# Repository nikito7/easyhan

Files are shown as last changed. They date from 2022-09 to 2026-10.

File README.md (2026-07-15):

# Easy HAN ®

Smart IoT Devices

- [```bridge``` rtuovertcp modbus tcp](./tasmota/bridge/)

- [```edpbox V1``` contadores inteligentes](./V1/)

- [```edpbox V2``` contadores inteligentes](./V2/)

- [```growatt``` inversor solar](./tasmota/growatt/)

- [```lorawan``` ttn edpbox han](./misc/lorawan/)

____
Sansana Smart Solutions ® Portugal

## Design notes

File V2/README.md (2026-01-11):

# HAN V2

https://github.com/nikito7/han-dev/tree/dev/tasmota/xdrv100

EB1:
https://u.easyhan.pt/v2/setup-v2/

Deve-se usar os ficheiros do u.easyhan.pt

Os ficheiros do github acima, são apenas para seguir o desenvolvimento.

# Override Settings

Tools > Manage filesystem <br>
Criar o ficheiro config.txt

```js
HanDelayWait 1000
HanDelayError 5000
HanTimeout 1500
HanRestart 0
TelePeriod 10
HanSkip 0,0,0,0,0,0,0,0,0,0,0,0,0,0,0
```

O ficheiro só é aplicado aos 30 segundos depois de iniciado.

# HanSkip

HanSkip 0,0,0,0,0,0,0,0,0,0,0,0,0,0,0

```js
1 - EB Type
2 - EMI Info
3 - Contract
4 - LP ID
5 - Clock
6 - Voltage. Current.
7 - Power. Power Factor mono.
8 - Power Factor tri. Frequency mono.
9 - kWh Energy Tarifas
10 - kWh Total Energy
11 - kWh L1 L2 L3 
12 - Reserved
13 - Load Profile
14 - Ciclo. Tarifa.
15 - ICP Status
```

Apenas Watts:

```js
HanSkip 1,1,1,1,1,1,0,1,1,1,1,1,1,1,1
```
Realtime Netmetering (qs):

```js
HanSkip 1,1,1,1,0,1,0,1,1,0,1,1,1,1,1
```

Tudo a cada 5min (script);

```js
>S

if (upsecs%300==0 and upsecs>100)
{
=>BackLog HanSkip 0,0; Delay 200; HanSkip 1,1,1,1,1,1,0,1,1,1,1,1,1,1,1
}
```

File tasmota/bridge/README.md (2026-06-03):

⚠️ Easy HAN E5.1 Enable pin GPIO16

V2: firmware *-tcp

https://u.easyhan.pt/v2/

V1: default

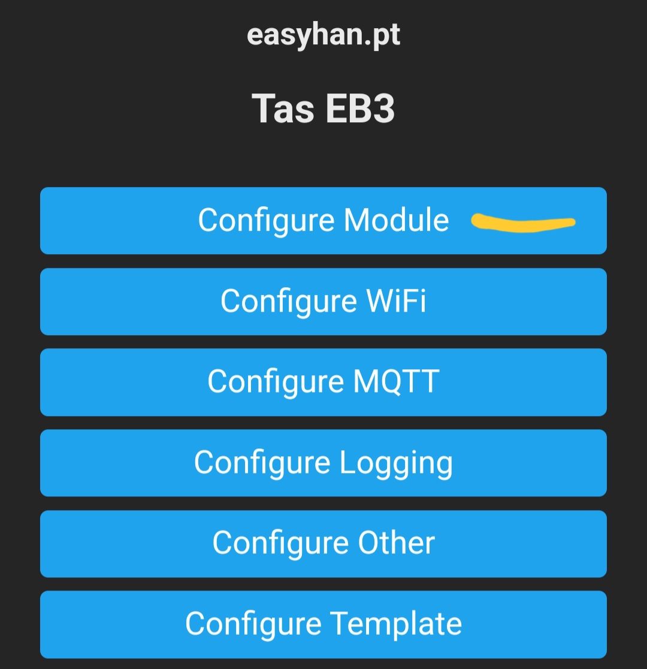
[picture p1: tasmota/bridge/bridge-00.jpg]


RTU over TCP:

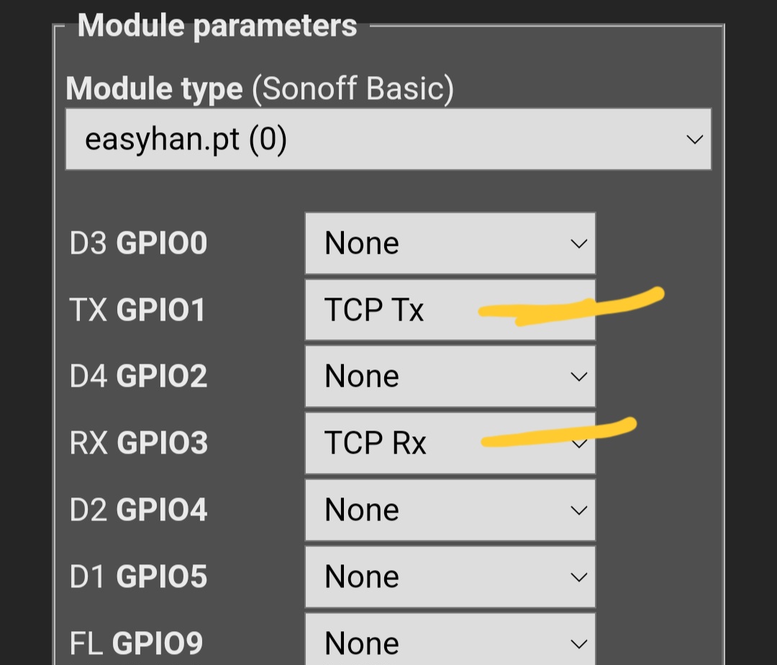
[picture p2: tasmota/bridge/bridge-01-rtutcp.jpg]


https://github.com/nikito7/easyhan/blob/dev/tasmota/bridge/Bridge-RTUoverTCP.js

Modbus TCP:

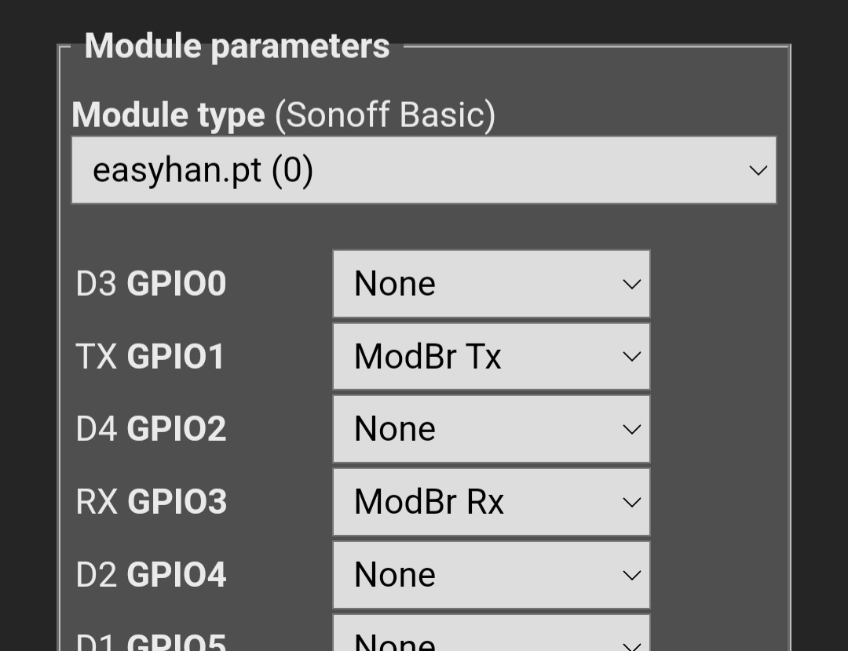
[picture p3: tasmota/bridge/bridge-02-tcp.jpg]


https://github.com/nikito7/easyhan/blob/dev/tasmota/bridge/Bridge-ModbusTCP.js

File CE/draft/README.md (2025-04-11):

# Links

https://europa.eu/youreurope/business/product-requirements/labels-markings/ce-marking/index_en.htm

# Technical documentation (draft)

**Product function:**

  Generic modbus to WiFi converter.

**Product names and models:**

- Easy HAN ® E5 WiFi
- Easy HAN ® B5 WiFi

**Product version**:

  5.4.1

**Markets:**

  Portugal, EU.

**PCB board design:**

  Coimbra, Portugal.

**PCB board manufacturing, components source and SMT assembly:**

  JLCPCB, China.

**Final prototype assembly:**

  Coimbra, Portugal.

**Status of development:**

  Final prototype.

2025-04-11

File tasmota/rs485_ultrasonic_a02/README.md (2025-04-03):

wires:

```
Red = 5V
Black = Ground
White = A+
Yellow = B-
```

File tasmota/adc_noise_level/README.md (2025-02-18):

https://circuitdigest.com/microcontroller-projects/interface-ky038-sound-sensor-with-esp32

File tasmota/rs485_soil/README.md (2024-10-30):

# Soil Sensor RS485

ZTS-3000-TR-WS-N01

# ESPHome

https://github.com/nikito7/easyhan/blob/dev/esphome/t44-x04-soil.yaml

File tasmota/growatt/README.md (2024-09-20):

Tutorial:

https://forum.cpha.pt/t/integrar-inversor-growatt-tl3-no-home-assistant/10672

 

FreeDS:

mqtt: freeds/growatt/SENSOR

---

Growatt inversor

Modbus RS485

---

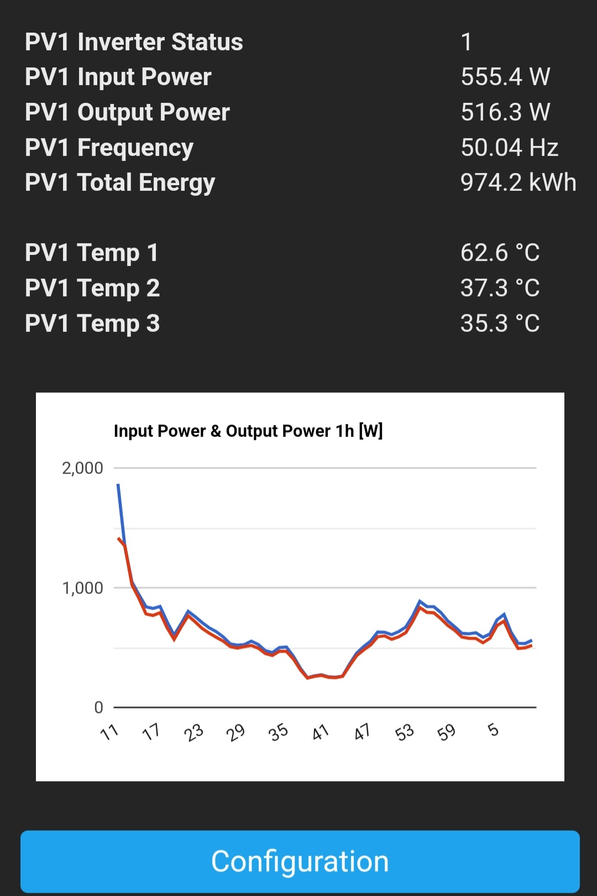
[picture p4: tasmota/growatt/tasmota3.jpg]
inverter tasmota


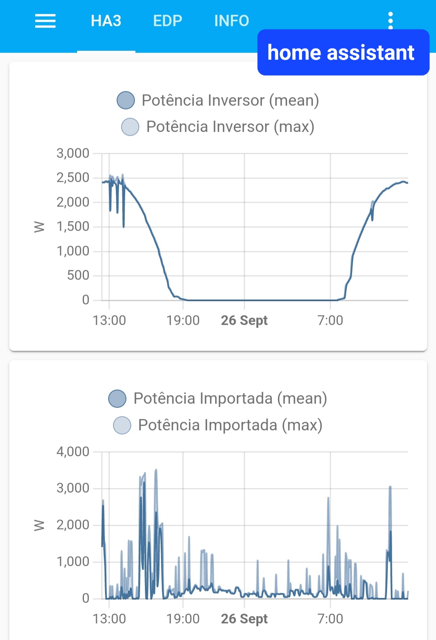
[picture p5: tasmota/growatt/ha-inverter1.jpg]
Easy HAN inverter


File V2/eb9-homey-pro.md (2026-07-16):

# Homey Pro

https://homey.app/

Requisitos:
- MQTT Broker (server)
- MQTT Client
- MQTT Hub (virtual devices)

# EB1 (monofásico)

```
{
  "measure_power": {
    "capability": "measure_power",
    "stateTopic": "tele/edpbox1/SENSOR",
    "setTopic": "",
    "valueTemplate": "EB1.API - EB1.APE",
    "outputTemplate": "",
    "displayName": "Power"
  },
  "meter_power.imported": {
    "capability": "meter_power.imported",
    "stateTopic": "tele/edpbox1/SENSOR",
    "setTopic": "",
    "valueTemplate": "EB1.TEI",
    "outputTemplate": "",
    "displayName": "Energy Import"
  },
  "meter_power.exported": {
    "capability": "meter_power.exported",
    "stateTopic": "tele/edpbox1/SENSOR",
    "setTopic": "",
    "valueTemplate": "EB1.TEE",
    "outputTemplate": "",
    "displayName": "Energy Export"
  }
}
```

# EB3 (trifásico)

```
{
  "measure_power": {
    "capability": "measure_power",
    "stateTopic": "tele/edpbox3/SENSOR",
    "setTopic": "",
    "valueTemplate": "EB3.API - EB3.APE",
    "outputTemplate": "",
    "displayName": "Power"
  },
  "meter_power.imported": {
    "capability": "meter_power.imported",
    "stateTopic": "tele/edpbox3/SENSOR",
    "setTopic": "",
    "valueTemplate": "EB3.TEI",
    "outputTemplate": "",
    "displayName": "Energy Import"
  },
  "meter_power.exported": {
    "capability": "meter_power.exported",
    "stateTopic": "tele/edpbox3/SENSOR",
    "setTopic": "",
    "valueTemplate": "EB3.TEE",
    "outputTemplate": "",
    "displayName": "Energy Export"
  }
}

# PV1

{
  "measure_power": {
    "capability": "measure_power",
    "stateTopic": "tele/pv1/SENSOR",
    "setTopic": "",
    "valueTemplate": "PV1.InputPower",
    "outputTemplate": "",
    "displayName": "Power"
  },
  "meter_power": {
    "capability": "meter_power",
    "stateTopic": "tele/pv1/SENSOR",
    "setTopic": "",
    "valueTemplate": "PV1.PV_Energy",
    "outputTemplate": "",
    "displayName": "Energy"
  }
}
```

_____
EOF

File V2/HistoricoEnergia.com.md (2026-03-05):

# historicoenergia.com

https://historicoenergia.com

Acrescentar os blocos de código ao Script, no sitio correcto.

# Script B5

```
>D 48
...
```
```js
;
TOK="token"
ID="ebhan"
T=0
E1=0
E2=0
E3=0
F=0
I=0
PF=0
```

EB3:

```
>T
...
```
```js
;
T=EB3#Tariff
E1=EB3#TET1
E2=EB3#TET2
E3=EB3#TET3
I=EB3#CL
F=EB3#FR
PF=EB3#PF
```

EB1:

```
>T
...
```
```js
;
T=EB1#Tariff
E1=EB1#TET1
E2=EB1#TET2
E3=EB1#TET3
I=EB1#CL1
F=EB1#FR
PF=EB1#PF
```

```
>S
...
```
```js
if (upsecs%181==0 and cnt>40)
{
print historicoenergia.com %2.0hh%:%2.0mm%:%2.0ss%
->WebQuery http://api.historicoenergia.com/api/webhook/mqtt?deviceId=%ID%&token=%TOK% POST {"P":%0ipwr%,"V":%1vt1%,"T":%0T%,"E1":%2E1%,"E2":%2E2%,"E3":%2E3%,"F":%1F%,"PF":%PF%,"I":%1I%}
}
```

# Script E5 basico

```
>S
...
```
```js
if (upsecs%181==0 and cnt>40)
{
print historicoenergia.com %2.0hh%:%2.0mm%:%2.0ss%
->WebQuery http://api.historicoenergia.com/api/webhook/mqtt?deviceId=DEVICE&token=TOKEN POST {"P":%0ipwr%,"V":%1vt1%}
}
```

# EOF

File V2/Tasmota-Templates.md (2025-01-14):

# Tasmota Templates

> B5.02
> ESP32-C6 N8

```{"NAME":"sd.c6.easyhan.pt","GPIO":[1,1,1,1,1,1,1,1,1,1,1,1,1,1,1,1,1,1,672,736,704,6720,1,1,0,0,0,0,0,0,0],"FLAG":0,"BASE":1}```

```{"NAME":"c6.easyhan.pt","GPIO":[1,1,1,1,1,1,1,1,1,1,1,1,1,1,1,1,1,1,1,1,1,1,1,1,0,0,0,0,0,0,0],"FLAG":0,"BASE":1}```

> X04v1.3
> ESP32-S3 N8

```{"NAME":"adc.ds.sd.s3.easyhan.pt","GPIO":[1,4704,4705,1,4707,1,1,1,1,1,1,1,1,1,1,1,1,1,1,1,1,1,1,672,736,704,6720,1312,1,1,1,1,1,1,1,1,1,1],"FLAG":0,"BASE":1}```

# EOF

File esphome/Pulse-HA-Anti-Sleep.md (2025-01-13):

```yaml
alias: Pulse Anti Sleep
description: ""
triggers:
  - trigger: state
    entity_id:
      - sensor.pulse_adc_in_raw
    for:
      hours: 0
      minutes: 0
      seconds: 1
conditions: []
actions:
  - action: button.press
    metadata: {}
    data: {}
    target:
      entity_id: button.pulse_esp_prevent_sleep
mode: single
```

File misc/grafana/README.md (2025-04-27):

https://grafana.com/grafana/dashboards/21369-han-lite-eb3/

Grafana Cloud exemplo:
https://github.com/nikito7/easyhan/discussions/11
Adaptar para uso local.

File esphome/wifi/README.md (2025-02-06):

Configurar WiFi via hotspot

1.

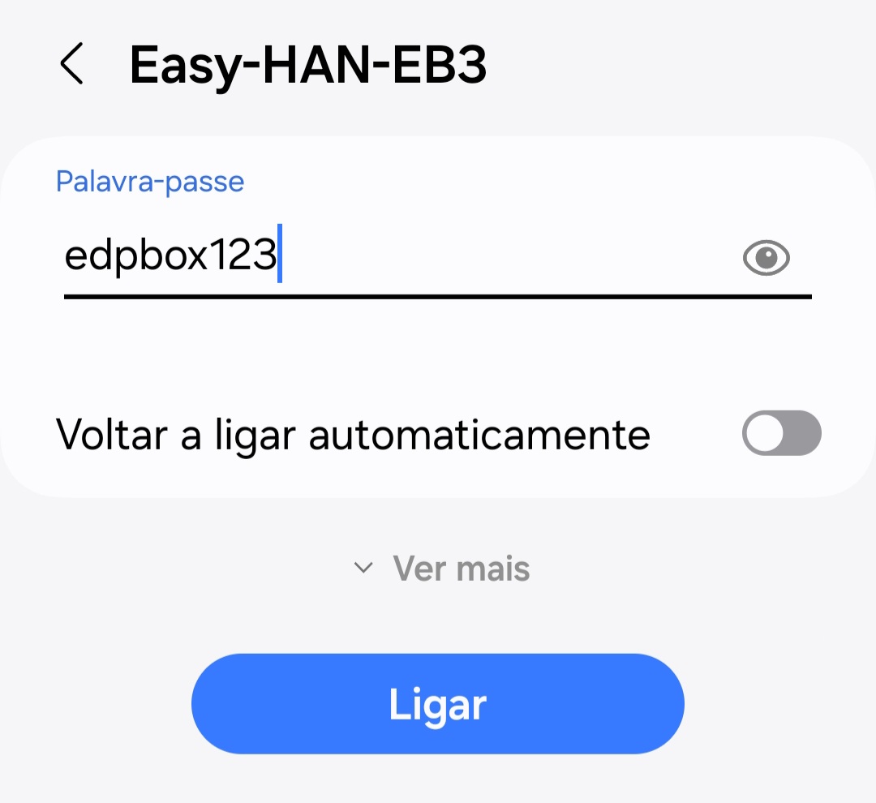
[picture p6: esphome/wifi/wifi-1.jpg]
easyhan.pt esphome


2.

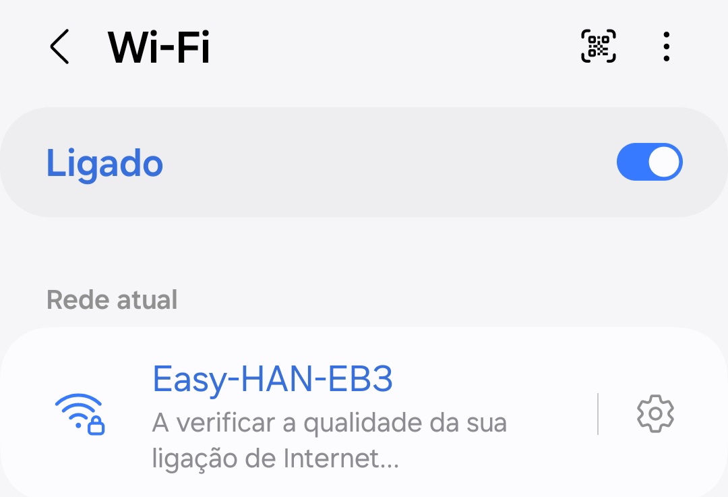
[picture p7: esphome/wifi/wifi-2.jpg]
easyhan.pt esphome


Insistir caso dê erro

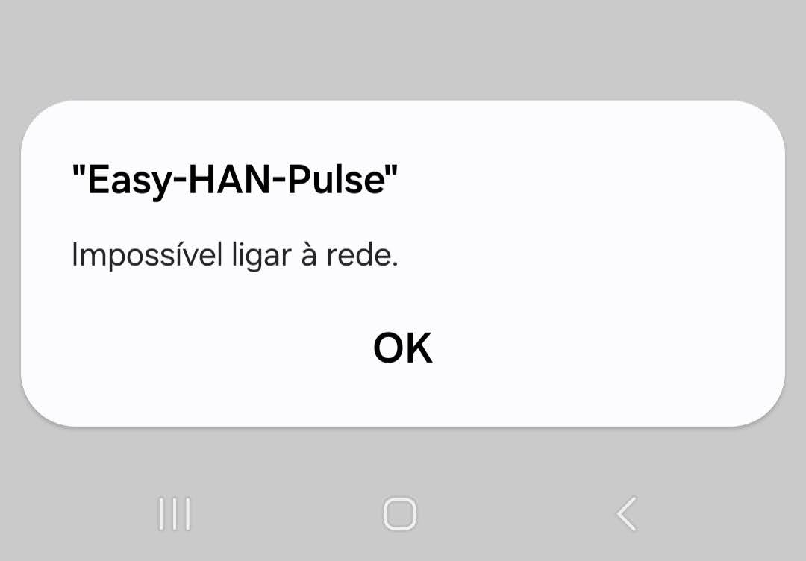
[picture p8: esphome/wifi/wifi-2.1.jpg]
easyhan.pt esphome


3.

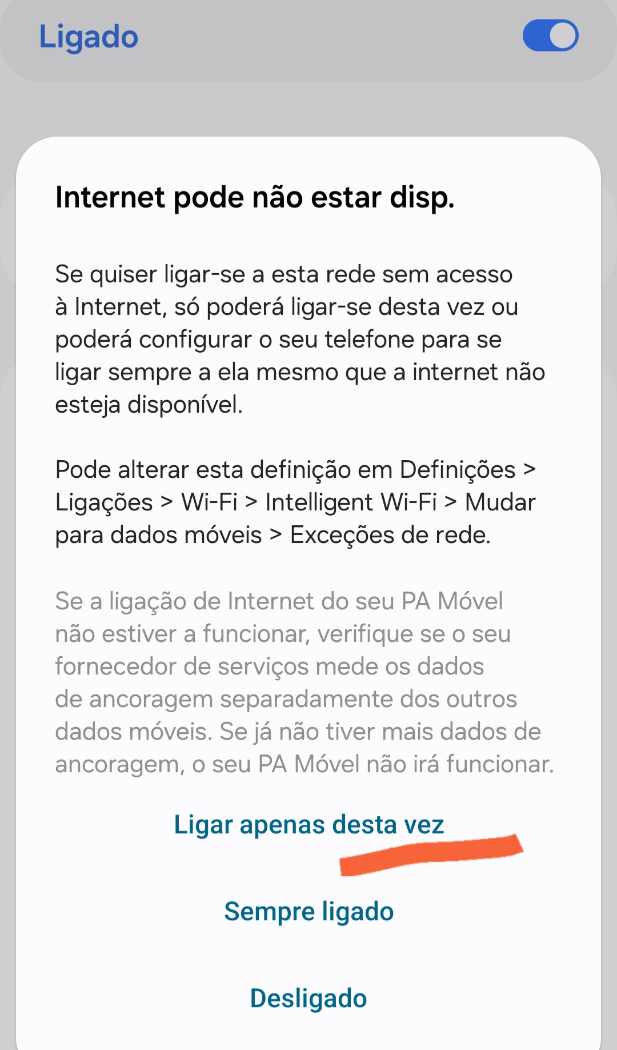
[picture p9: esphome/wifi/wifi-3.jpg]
easyhan.pt esphome


4.

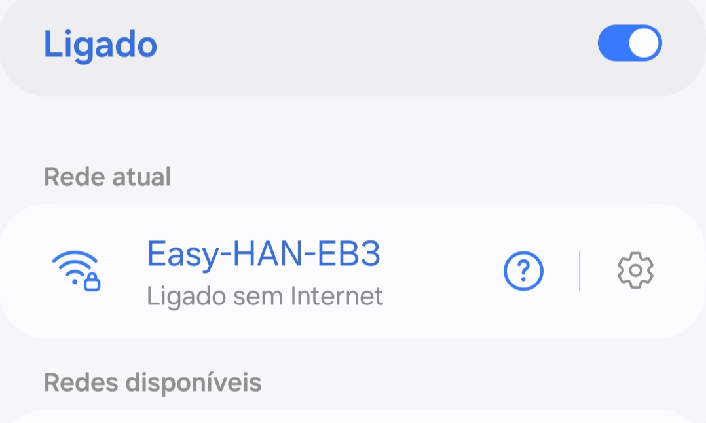
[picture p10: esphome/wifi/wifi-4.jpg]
easyhan.pt esphome


5.

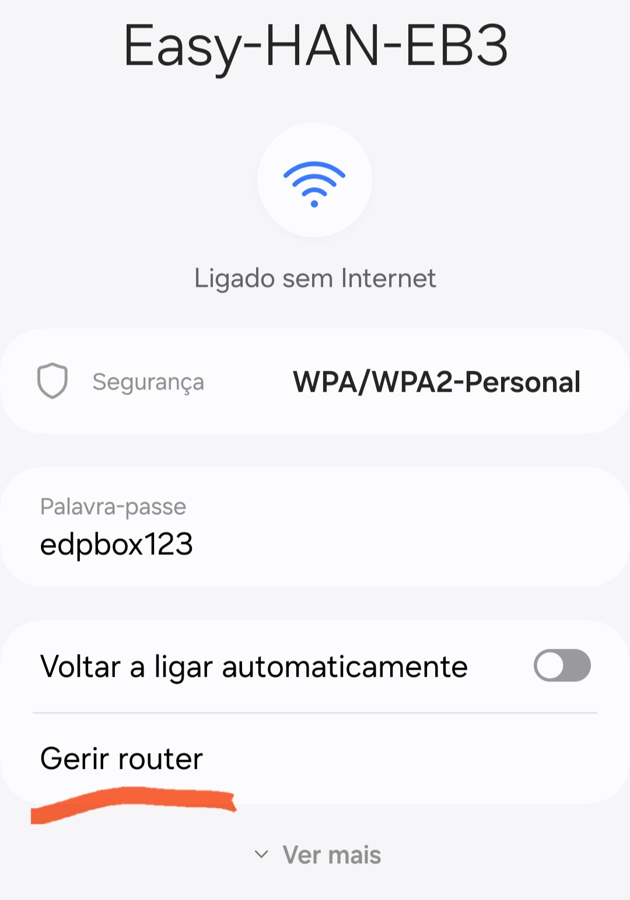
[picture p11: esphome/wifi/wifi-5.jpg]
easyhan.pt esphome


ou

http://192.168.4.1/

6.

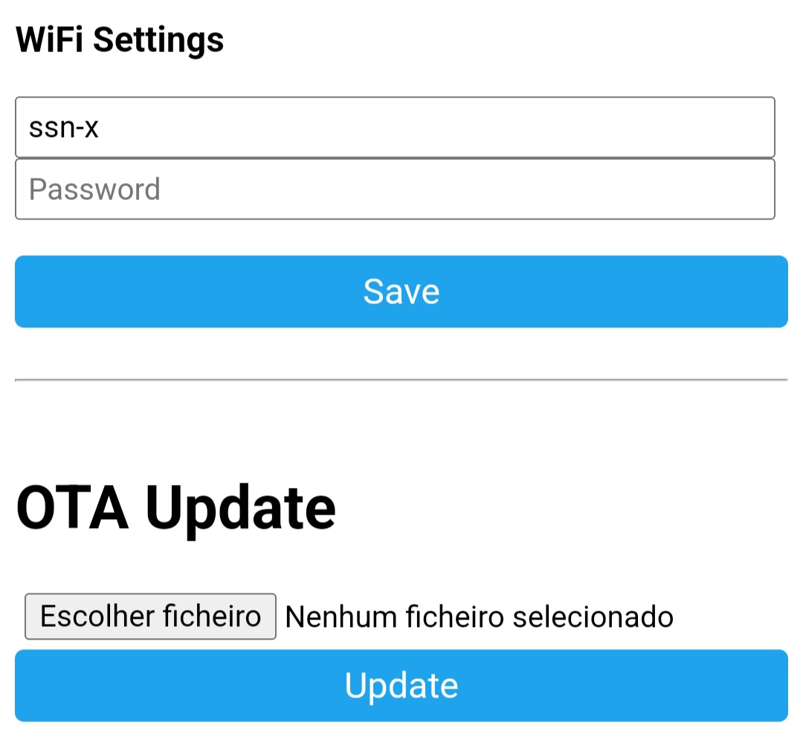
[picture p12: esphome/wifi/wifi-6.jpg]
easyhan.pt esphome


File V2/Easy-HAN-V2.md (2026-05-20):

# Easy HAN ® 
# Firmware V2 
# ESP8266

As imagens são apenas uma referência e podem não estar actualizadas.

Tasmota > Consoles > Console

1.

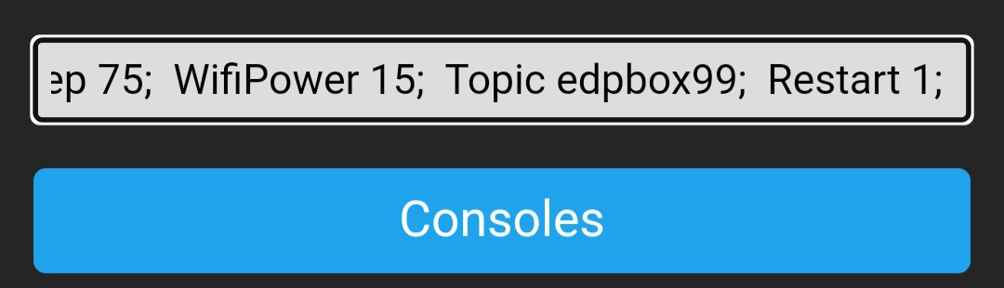
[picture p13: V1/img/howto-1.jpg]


(linha única. caso o copy-paste não funcione correctamente, corrigir primeiro)

1.1. Defaults

```js
Backlog0 
TimeZone 99; 
TimeDST 0,0,3,1,1,60; 
TimeSTD 0,0,10,1,2,0; 
MqttUser none; 
MqttPassword none; 
MqttClient Easy_HAN_%06X; 
WebLog 2;
SerialLog 0;
Sleep 75; 
WifiPower 15;
Topic edpbox99; 
Restart 1; 
```

1.2. Manter mqtt

```js
Backlog0 
TimeZone 99; 
TimeDST 0,0,3,1,1,60; 
TimeSTD 0,0,10,1,2,0; 
WebLog 2;
SerialLog 0;
Sleep 75; 
WifiPower 15;
Restart 1; 
```

2. 

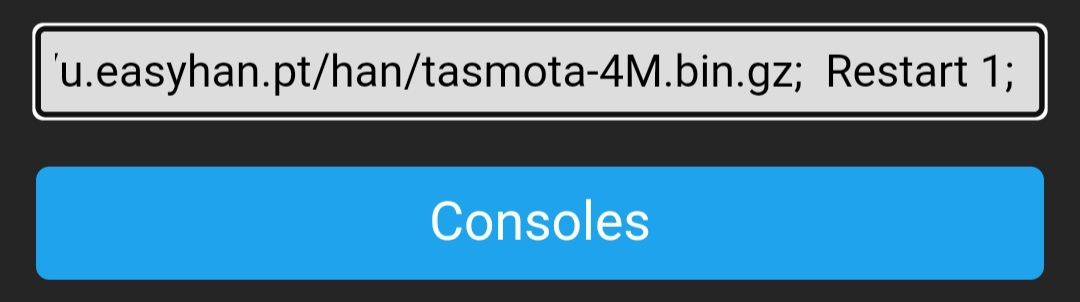
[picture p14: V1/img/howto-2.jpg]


(linha única)

```js
Backlog0 
Hostname Easy-HAN-EB99; 
Template {"NAME":"easyhan.pt","GPIO":[1,1,1,1,1,1,1,1,1,1,1,1,1,1],"FLAG":0,"BASE":18}; 
Module 0; 
WifiConfig 2; 
OtaUrl http://u.easyhan.pt/v2/tasmota-4M.bin.gz; 
Restart 1; 
``` 

3. Upload files (se necessário)

Monofásico:

http://u.easyhan.pt/v2/setup-v2/EB1/

Trifásico:

http://u.easyhan.pt/v2/setup-v2/EB3/

Zip com tudo:

https://u.easyhan.pt/v2/setup-v2/

HAN-V2-*****.zip

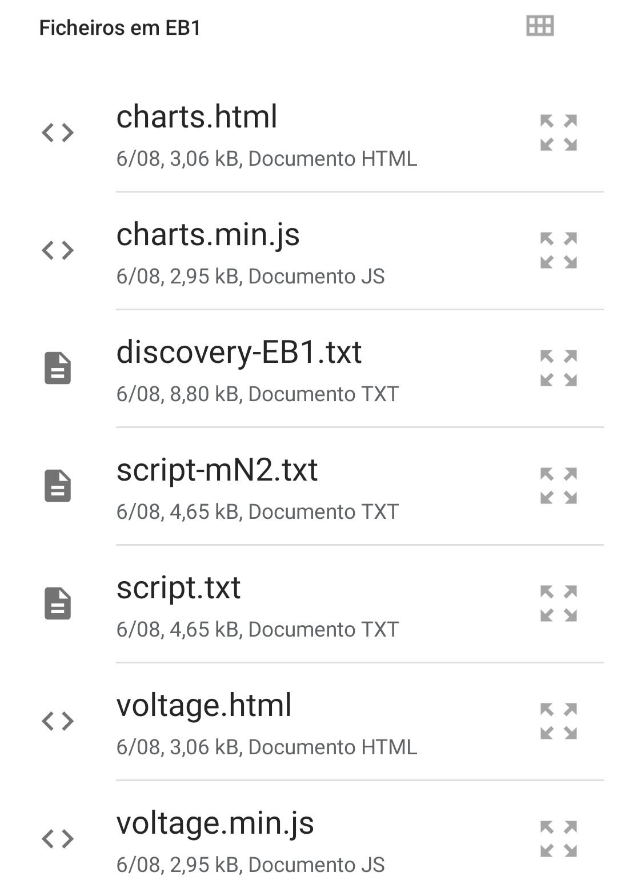
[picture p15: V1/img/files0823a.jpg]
files


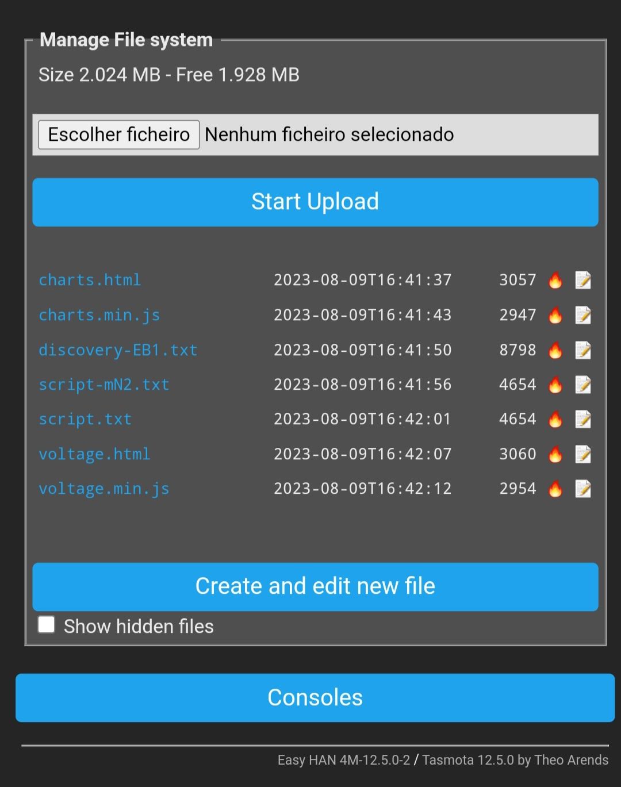
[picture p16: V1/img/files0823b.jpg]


4. OTA Upgrade

```http://u.easyhan.pt/v2/tasmota-4M.bin.gz```

![Easy HAN](../V1/img/howto-4.jpg)

...

5. Enable Script

Na consola:

```js
Backlog0 Script 1; SaveData 9; Restart 1;
```
Enter

<hr>

---

https://easyhan.pt/?v2

Easy HAN ® V2

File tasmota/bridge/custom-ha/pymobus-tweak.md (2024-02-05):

```
docker exec -it homeassistant /bin/bash
```

```
find / -name register_read_message*
```

4 or 12 (it may make HA slow)
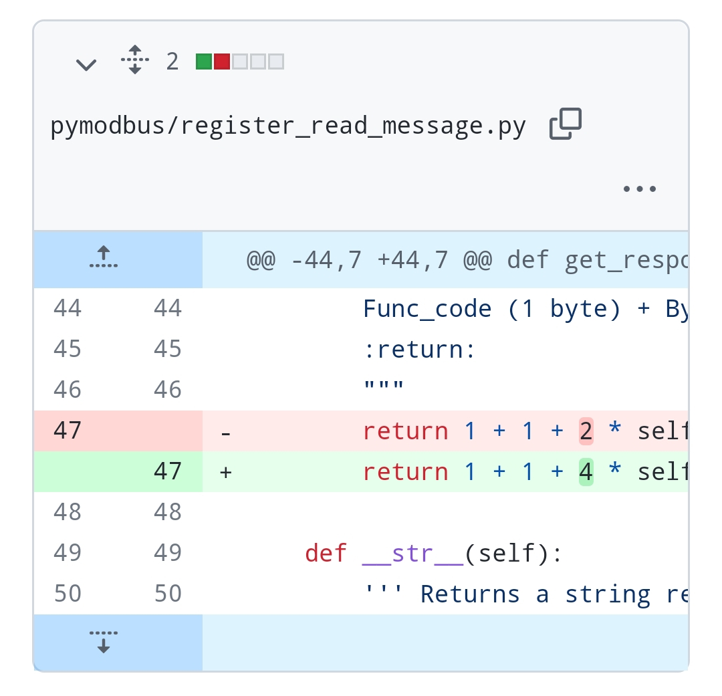
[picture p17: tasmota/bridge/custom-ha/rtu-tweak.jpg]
rtu tweak


---
only run if you understand it 
```
#! /bin/bash

echo "This script is executed in the homeassistant container"; 
env;
# Check if the file needs to be modified
cat /usr/local/lib/python3.11/site-packages/pymodbus/register_read_message.py  | grep "return 1 + 1 + 2 \* self.count"
if [ $? -eq 0 ]
then
	echo "Going to replace and restart"
	sed -i 's/return 1 + 1 + 2 \* self.count/return 1 + 1 + 4 \* self.count/g' /usr/local/lib/python3.11/site-packages/pymodbus/register_read_message.py 
	rm -rf  /usr/local/lib/python3.11/site-packages/pymodbus/__pycache__/
	sleep 5
	# Reboot the home assistant
#	reboot
	curl -X POST -H "Authorization: Bearer <colocar_Aqui_token_do_home_assistant_para_reiniciar>" -H "Content-Type: application/json" -d '{}' http://localhost:8123/api/services/homeassistant/restart	
else
	echo "All ok"
fi
```

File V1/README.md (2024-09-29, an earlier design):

# V2

https://github.com/nikito7/easyhan/tree/dev/V2

# Easy HAN ® RS485

Leitor WiFi da porta HAN.

Medidor de consumo via porta HAN. 

Acesso aos dados do contador.

Acesso ao Diagrama de Carga (netmetering)

Adaptador Modbus para WiFi.

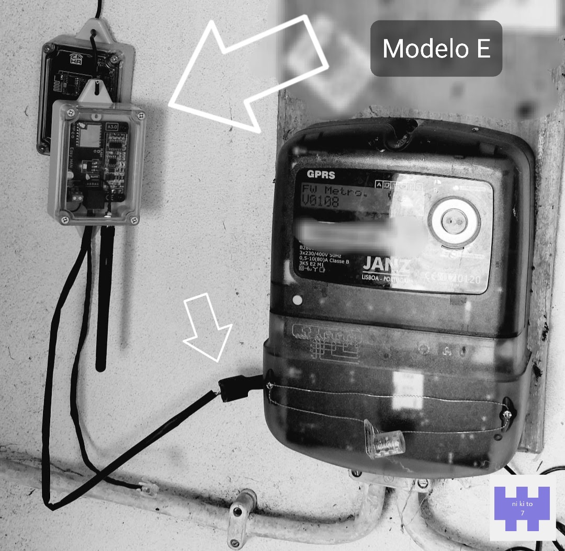
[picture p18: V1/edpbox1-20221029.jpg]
edpbox


Mais info no forum:

https://forum.cpha.pt/t/easy-han-rs485-edpbox-modbus/9977

# Contadores

Monofásicos:

- Kaifa MA109H

- Kaifa MA109P

- Janz C3801 GPRS

- Landis+Gyr ZCXe110 S3

- Landis+Gyr ZCXe110 S5

- Sagemcom CX1000-6

- Sagemcom S212

- Ziv

Trifásicos:

- Janz B2801 GPRS

- Janz B2801 PLC

- Landis+Gyr ZMXe310 S3

- Landis+Gyr ZMXe310 S5

- Sagemcom CX2000-9

- Sagemcom T215

- Ziv

Notas:

- Landis+Gyr & Ziv: Serial mN1/mN2.

- Sagem's: ```Sleep 75``` e ```WifiPower 12```.

# Tasmota

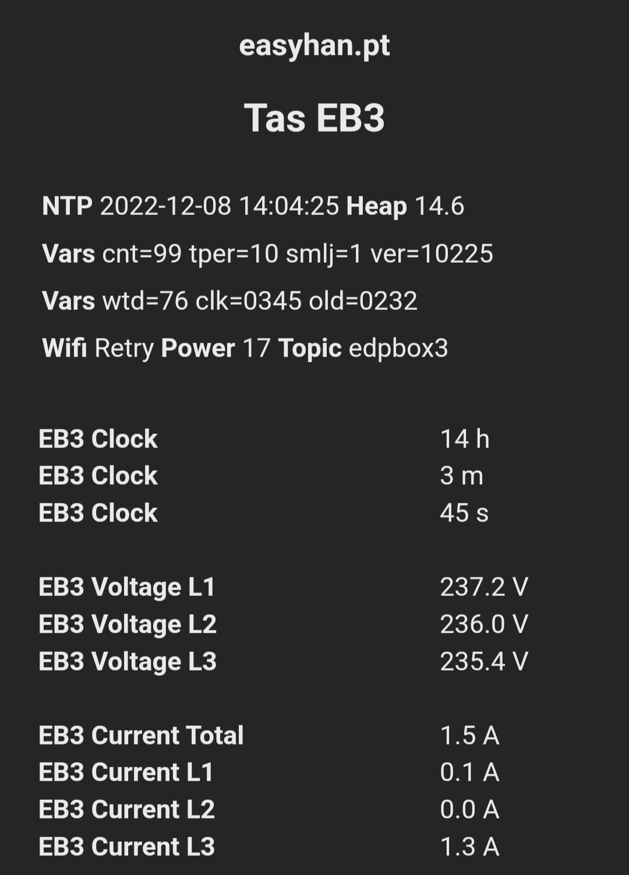
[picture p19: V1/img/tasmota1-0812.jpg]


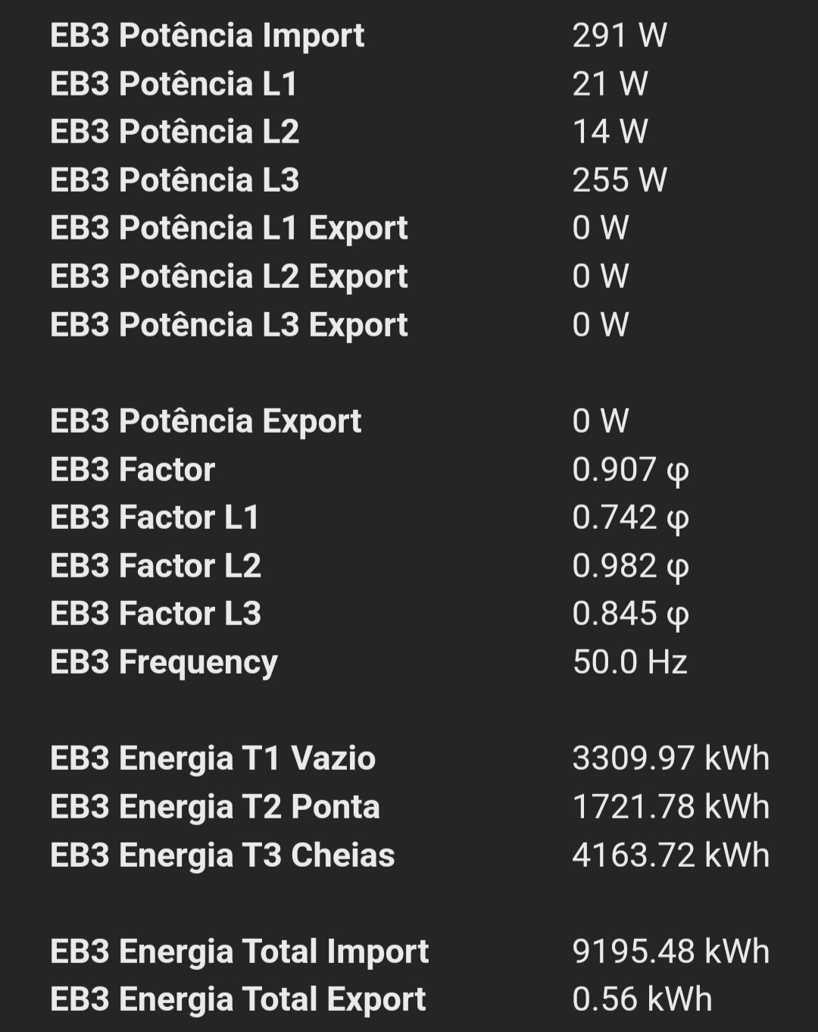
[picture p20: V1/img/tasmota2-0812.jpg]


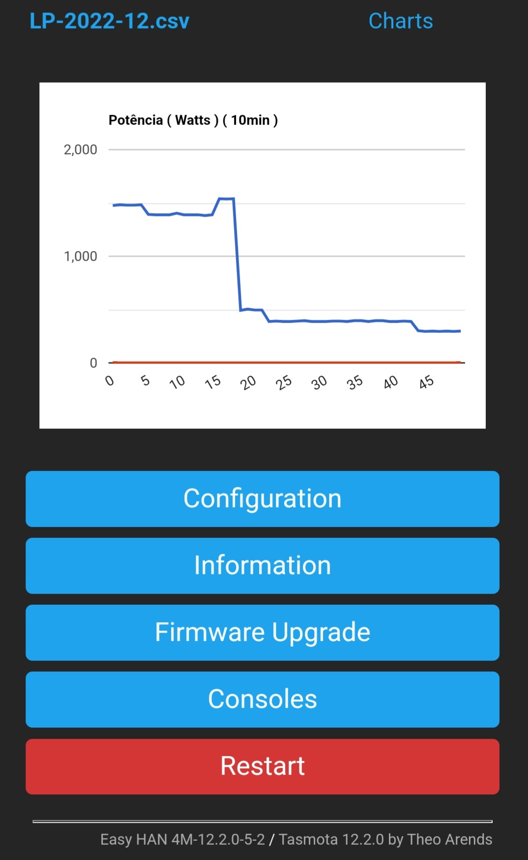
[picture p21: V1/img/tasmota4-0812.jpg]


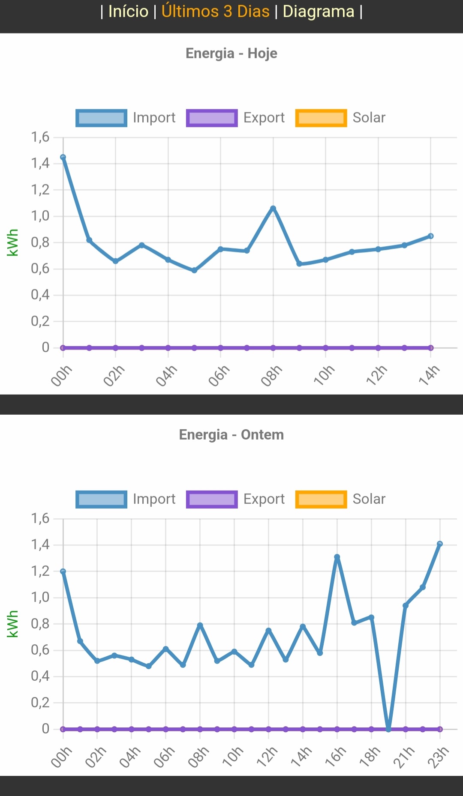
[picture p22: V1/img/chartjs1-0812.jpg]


Easy HAN

# Home Assistant

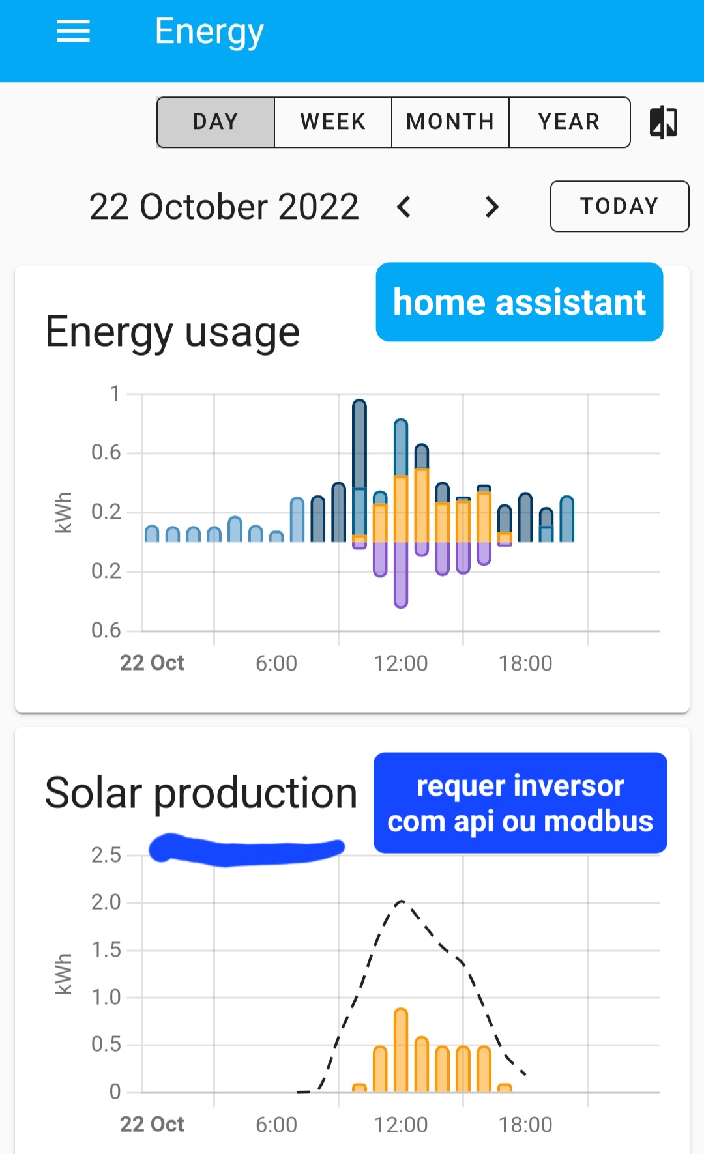
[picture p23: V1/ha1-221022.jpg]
Easy HAN HA


---

 

https://easyhan.pt

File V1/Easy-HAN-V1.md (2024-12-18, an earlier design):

# Easy HAN ® V1

Tasmota > Consoles > Console

1.

Easy HAN

(linha única)

manter mqtt:

```js
Backlog 
TimeZone 99; 
TimeDST 0,0,3,1,1,60; 
TimeSTD 0,0,10,1,2,0; 
MqttClient Easy_HAN_%06X; 
WebLog 3; 
Sleep 75; 
WifiPower 0;
Topic edpbox99; 
Restart 1; 
```

default:

```js
Backlog 
TimeZone 99; 
TimeDST 0,0,3,1,1,60; 
TimeSTD 0,0,10,1,2,0; 
MqttUser none; 
MqttPassword none; 
MqttClient Easy_HAN_%06X; 
WebLog 3; 
Sleep 75; 
WifiPower 0;
Topic edpbox99; 
Restart 1; 
```

2. 

Easy HAN

(linha única)

```js
Backlog 
Hostname Easy-HAN-EB99; 
Template {"NAME":"easyhan.pt","GPIO":[1,1,1,1,1,1,1,1,1,1,1,1,1,1],"FLAG":0,"BASE":18}; 
Module 0; 
WifiConfig 2; 
OtaUrl http://u.easyhan.pt/v2/tasmota-4M-v1.bin.gz; 
Restart 1; 
``` 

3. Upload files

Monofásico:
http://u.easyhan.pt/v1/setup-v1/EB1/

Trifásico:
http://u.easyhan.pt/v1/setup-v1/EB3/

Zip com tudo:
https://u.easyhan.pt/v1/setup-v1/HAN.zip

files

Easy HAN

4. OTA Upgrade

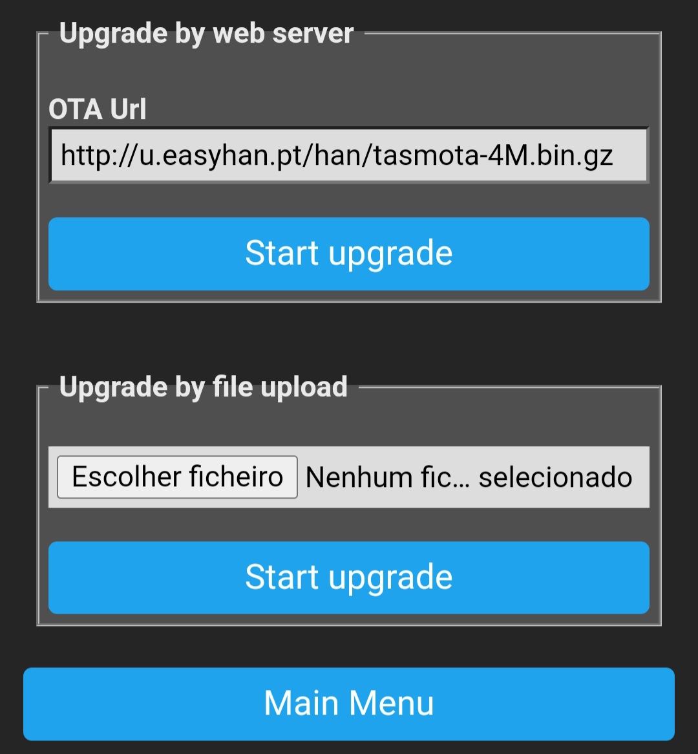
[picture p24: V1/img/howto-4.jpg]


...

5. Enable Script

```js
Backlog Script 1; SaveData 9; Restart 1;
```

<hr>

# Sagem

```js
Backlog Sleep 75; WifiPower 15; 
```

---

# mN2 (Stop Bits 2)

Ziv e alguns Landis

Implica a existência dos dois scripts

(linha única)

```js
Backlog 
UfsRename script.txt,script-mN1.txt; 
UfsRename script-mN2.txt,script.txt; 
Script 1; Restart 1;
```

Voltar ao mN1:

(linha única)

```js
Backlog 
UfsRename script.txt,script-mN2.txt; 
UfsRename script-mN1.txt,script.txt; 
Script 1; Restart 1;
```

---

https://easyhan.pt

Easy HAN ® RS485

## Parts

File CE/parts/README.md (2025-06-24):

SMT Parts:

- jlcpcb.com

Extra Parts:

- Capacitor 4700uF Solid

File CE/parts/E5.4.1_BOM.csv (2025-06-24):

ID | Name | Designator | Footprint | Quantity | Manufacturer Part | Manufacturer | Supplier | Supplier Part | Price | Value
1 | CONN-TH_2P-P3.81_KF124-3.81-2P | P1,P2,P3 | CONN-TH_2P-P3.81_KF124-3.81-2P | 3 | WJ124-3.81-2P | KANGNEX | LCSC | C69811 | 0.146
2 | C1206 | C8E | C1206 | 1 | CL31A107MQHNNNE | SAMSUNG | LCSC | C15008 | 0.068 | 100uF
3 | R0402 | R81 | R0402 | 1 | 0402WGF1004TCE | UNI-ROYAL | LCSC | C26083 | 0.001 | 1MΩ
4 | SMA_L4.2-W2.6-LS5.3-RD | U1 | SMA_L4.2-W2.6-LS5.3-RD | 1 | SS14 | MDD | LCSC | C2480 | 0.015
5 | R0603 | R0 | R0603 | 1 | 0603WAF0000T5E | UNI-ROYAL | LCSC | C21189 | 0.001 | 0Ω
6 | C0603 | C75,C73,C3,C1,C2 | C0603 | 5 | CC0603KRX7R9BB104 | YAGEO | LCSC | C14663 | 0.002 | 100nF
7 | C0603 | C11,C10,C4,C5,C71,C74 | C0603 | 6 | CL10A106KP8NNNC | SAMSUNG | LCSC | C19702 | 0.006 | 10uF
8 | WIRELM-SMD_ESP-07S | ESP | WIRELM-SMD_ESP-07S | 1 | ESP-07S | Ai-Thinker | LCSC | C82895 | 2.939
9 | TPS63051RMWR | U4 | QFN-12_L2.5-W2.5-P0.50-TL | 1 | TPS63051RMWR | TI | LCSC | C139412 | 0.777
10 | 1.5uH | UH | IND-SMD_L2.5-W2.0_SWPA252010S1R0MT | 1 | MAI252010S-1R5MT | ceaiya | LCSC | C520239 | 0.037
11 | MAX3485AEASA+T | MAX | SO-8_L4.9-W3.9-P1.27-LS5.9-BL | 1 | MAX3485AEASA+T | ADI/MAXIM | LCSC | C94609 | 0.625
12 | LED0603-RD | L2,PWR | LED0603-RD | 2 | KT-0603R | KENTO | LCSC | C2286 | 0.006
13 | R0603 | R6,R7 | R0603 | 2 | 0603WAF4701T5E | UNI-ROYAL | LCSC | C23162 | 0.001 | 4.7kΩ

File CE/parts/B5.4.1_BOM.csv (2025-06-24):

ID | Name | Designator | Footprint | Quantity | Manufacturer Part | Manufacturer | Supplier | Supplier Part | Price | Value
1 | CONN-TH_2P-P3.81_KF124-3.81-2P | P1,P2,P3 | CONN-TH_2P-P3.81_KF124-3.81-2P | 3 | WJ124-3.81-2P | KANGNEX | LCSC | C69811 | 0.147
2 | C0603 | C13,C12,E.C1,D.C1,D.C4,C2 | C0603 | 6 | CC0603KRX7R9BB104 | YAGEO | LCSC | C14663 | 0.002 | 100nF
3 | SMA_L4.2-W2.6-LS5.3-RD | D2 | SMA_L4.2-W2.6-LS5.3-RD | 1 | SS14 | MDD | LCSC | C2480 | 0.016
4 | R0402 | E.R1,R81 | R0402 | 2 | 0402WGF1004TCE | UNI-ROYAL | LCSC | C26083 | 0.001 | 1MΩ
5 | TF-04A | CARD1 | TF-SMD_TF-04A | 1 | TF-04A |  | LCSC | C145799 | 0.213
6 | C0603 | E.C3,C11,D.C5,D.C6,D.C2,D.C3 | C0603 | 6 | CL10A106KP8NNNC | SAMSUNG | LCSC | C19702 | 0.006 | 10uF
7 | C0805 | E.C2 | C0805 | 1 | CL21A226MAQNNNE | SAMSUNG | LCSC | C45783 | 0.022 | 22uF
8 | R0603 | R2 | R0603 | 1 | 0603WAF1002T5E | UNI-ROYAL | LCSC | C25804 | 0.001 | 10kΩ
9 | ESP32-C6-WROOM-1U-N8 | ESP | WIFIM-SMD_28P-L19.2-W18.0-P1.27-TL | 1 | ESP32-C6-WROOM-1U-N8 |  | LCSC | C18212191
10 | TPS63051RMWR | TPS | QFN-12_L2.5-W2.5-P0.50-TL | 1 | TPS63051RMWR | TI | LCSC | C139412 | 0.709
11 | 1.5uH | UH | IND-SMD_L2.5-W2.0_SWPA252010S1R0MT | 1 | MAI252010S-1R5MT | ceaiya | LCSC | C520239 | 0.041
12 | MAX3485AEASA+T | MAX | SO-8_L4.9-W3.9-P1.27-LS5.9-BL | 1 | MAX3485AEASA+T | ADI/MAXIM | LCSC | C94609 | 0.624
13 | LED0603-RD | L2,PWR | LED0603-RD | 2 | KT-0603R | KENTO | LCSC | C2286 | 0.006
14 | R0603 | R6,R7 | R0603 | 2 | 0603WAF4701T5E | UNI-ROYAL | LCSC | C23162 | 0.001 | 4.7kΩ

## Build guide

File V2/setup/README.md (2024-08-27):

setup files backup.

Updated:
https://u.easyhan.pt/v2/setup-v2/

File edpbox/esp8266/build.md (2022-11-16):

https://github.com/nikito7/edpbox/tree/dev/tasmota/esp8266

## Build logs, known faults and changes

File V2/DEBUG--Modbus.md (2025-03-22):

Desactivar o plugin V2:

- Configuration > Template
- Num gpio livre escolher > TCP TX

usar um script debug

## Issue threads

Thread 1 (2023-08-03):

Calculation LP Export Inc,LP6_EXP

jgracio, 2023-08-03:
Can you please check this parameter, as it is much lower than the value extracted from e-redes?
Thanks

nikito7, 2023-08-03:
No e-redes dividir por 4.

Easy HAN: kWh
E-Redes: kW

jgracio, 2023-08-03:
Obrigado pela rapiddíssima resposta
O cálculo da energia exportanda em cada período de 15 minutos parece ter uma manipulação que leva a ser atenuada e a perder precisão. Recorrendo apenas ao meu EasyHan no Tasmota posso ver o dia de hoje:

No diagrama de Energia Hoje destaca-se que exportei energia cerca das 13:00 que àquela hora é bem maior que as energia importada ou exportada a qualquer hora.

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

Depois, no diagrama energia 30 dias referente a este mês, copiei apenas o dia de hoje (bem sei que as escalas dos gráficos são diferentes)

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

Mas nota-se que a energia exportada às 13:00 não é relevante relativamente a nenhuma das restantes horas do dia já que sofre uma atenuação. O mesmo se passou no dia de ontem.

Esta atenuação e perda de precisão é o valor que recebo no HA via MQTT e a que aparece no ficheiro CSV.

Obrigado pela paciência

nikito7, 2023-08-03:
Havia um bug quando passei de Wh a kWh.

Isso também não é perfeito. (Se houver reboots)

O diagrama de carga tem 15min de atraso.

jgracio, 2023-08-03:
Obrigado
O que tenho que fazer para corrigir o bug na minha configuração?

nikito7, 2023-08-03:
Acho que ainda não percebi o problema.

LP*csv
Valores absolutos e reais.
Pode falhar linhas.
De resto é o diagrama de carga real.
```js
2023-08-03T07:15,0.134,0.002
2023-08-03T07:30,0.012,0.021
2023-08-03T07:45,0.003,0.043
2023-08-03T08:00,0.019,0.058
2023-08-03T08:15,0.004,0.119
2023-08-03T08:30,0.017,0.132
2023-08-03T08:45,0.005,0.183
2023-08-03T09:00,0.010,0.215
2023-08-03T09:15,0.005,0.251
2023-08-03T09:30,0.010,0.286
2023-08-03T09:45,0.001,0.362
2023-08-03T10:00,0.034,0.344
2023-08-03T10:15,0.001,0.416
2023-08-03T10:30,0.695,0.072
2023-08-03T10:45,0.698,0.067
2023-08-03T11:00,0.760,0.000
2023-08-03T11:15,0.735,0.000
2023-08-03T11:30,0.718,0.000
2023-08-03T11:45,0.037,0.522
2023-08-03T12:00,0.000,0.578
2023-08-03T12:15,0.000,0.597
2023-08-03T12:30,0.071,0.524
2023-08-03T12:45,0.000,0.561
2023-08-03T13:00,0.001,0.581
2023-08-03T13:15,0.014,0.556
2023-08-03T13:30,0.006,0.581
2023-08-03T13:45,0.002,0.587
2023-08-03T14:00,0.002,0.604
2023-08-03T14:15,0.000,0.602
2023-08-03T14:30,0.000,0.601
2023-08-03T14:45,0.001,0.578
2023-08-03T15:00,0.001,0.544
2023-08-03T15:15,0.000,0.529
2023-08-03T15:30,0.008,0.492
2023-08-03T15:45,0.001,0.490
2023-08-03T16:00,0.639,0.106
2023-08-03T16:15,0.820,0.000
2023-08-03T16:30,0.799,0.000
2023-08-03T16:45,0.807,0.000
2023-08-03T17:00,0.841,0.000
2023-08-03T17:15,0.875,0.006
2023-08-03T17:30,0.000,0.288
2023-08-03T17:45,0.000,0.259
2023-08-03T18:00,0.001,0.227
2023-08-03T18:15,0.035,0.155
2023-08-03T18:30,0.002,0.113
2023-08-03T18:45,0.035,0.082
2023-08-03T19:00,0.038,0.042
2023-08-03T19:15,0.011,0.021
2023-08-03T19:30,0.046,0.008
2023-08-03T19:45,0.064,0.003
2023-08-03T20:00,0.041,0.001
2023-08-03T20:15,0.074,0.000
2023-08-03T20:30,0.171,0.000
2023-08-03T20:45,0.038,0.000
```

0d.csv
Precisão só de duas décimas.
Mas não influencia nada (de relevante)  no HA.
Se fizer reboot acumula na hora a seguir.
```js
2023-08-03,Import,Export
00h,0.13,0.00
01h,0.20,0.00
02h,0.14,0.00
03h,0.13,0.00
04h,0.12,0.00
05h,0.13,0.00
06h,0.11,0.00
07h,0.11,0.00
08h,0.17,0.12
09h,0.03,0.65
10h,0.05,1.25
11h,2.15,0.55
12h,1.50,1.09
13h,0.07,2.27
14h,0.02,2.33
15h,0.00,2.32
16h,0.65,1.62
17h,3.27,0.00
18h,0.88,0.78
19h,0.11,0.39
20h,0.16,0.04
```

jgracio, 2023-08-03:
Quando vejo o gráfico do HA a energia exportada aparece-me o mesmo que aparece o CSV e no diagrama de 30 dias. No diagrama diário está compatível com a integração da potencia exportada

nikito7, 2023-08-03:
O pico que tiveste no gráfico, não sei o motivo.

Mas o gráfico de 24h é baseado no "Energia Total Export". Precisão 2 décimas.

O de 30dias é baseado nos LP**
Precisão 3 decimas.

A Precisão não iria causar o pico.

Se usas o HA podes ignorar o gráfico das 24h...

nikito7, 2023-08-03:
Se o Easy HAN fizer reboot acontece coisas estranhas nesses gráficos internos...

nikito7, 2023-08-03:
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

jgracio, 2023-08-03:
Eu pretendo usar apenas o HA mas as curvas de exportação não estão corretas
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

nikito7, 2023-08-03:
"Calculation LP Export Inc,LP6_EXP"

Não há qualquer calculo nisto, valores reais.
Mas não são iguais à e-redes.

Os da e-redes são manipulados (*4).

De resto o importante é o que aparece no HA.

A parte dos LP precisa de um yaml adicional

jgracio, 2023-08-03:
O meu yaml no HA é:
`
    - name: "Contador - Quarto Hora Exportação"
      unique_id: EB1_LP6_EXP
      state_topic: "tele/contador_pp/SENSOR"
      value_template: >-
          {% set x = value_json.EB1.LP6_EXP|float(0) %}
          {% if x >= 0 %}
            {{ x }}
          {% endif %}
      unit_of_measurement: "kWh"
      device_class: energy`

nikito7, 2023-08-03:
Esse sensor só por si não faz nada.

Já agora tens a parte das contas?

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

jgracio, 2023-08-03:
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

nikito7, 2023-08-03:
https://gist.github.com/nikito7/034a28d1035cb236171e9cd78e18843a

nikito7, 2023-08-03:
https://github.com/nikito7/easyhan/blob/dev/edpbox/eb1-script.js

nikito7, 2023-08-03:
Por aqui aparentemente está tudo bem.

Tens de actualizar o script e yaml

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

jgracio, 2023-08-03:
O yaml que uso é identico e o script Tasmota que tenho instalado
é o da semana passada

nikito7, 2023-08-03:
Dizer o ver= que aparece no topo do tasmota ajuda qualquer coisa

jgracio, 2023-08-03:
é a versão anterior 10283

jgracio, 2023-08-03:
Vou ver se descubro o que se passa ou arranjar uma alternativa.  Obrigado pela ajuda mas pelos visto não é um problema da configuração

nikito7, 2023-08-03:
Havia esse problema apenas no saldo.

https://github.com/nikito7/easyhan/commit/53c0146aa84706a6e9a7485901b4957d3c9f3f46

jgracio, 2023-08-03:
No meu CSV não aparece a exportação no periodos das 13:00 (que ocorreu na realidade) -> este é só um exemplo porque esta atenuação ocorre sempre.

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

nikito7, 2023-08-03:
Só que esses valores são reais....

Quanto muito pode ser o contador a causar isso....

nikito7, 2023-08-03:
Se tiveres consumo residual é dificil ver.

Se tiveres poucos painéis. A casa pode absorver tudo.

Acho que o código não tem bug.

É uma questão de percepção dos dados.

Ou posso estar enganado 😅

nikito7, 2023-08-03:
Também posso estar a ler o register errado

nikito7, 2023-08-03:
Compara com o xlsx da e-redes (dividir por 4) tem de bater certo

jgracio, 2023-08-03:
Se fosse um problema do contador não seria possível aparecerem dados reais nos gráficos diários?

jgracio, 2023-08-03:
> Compara com o xlsx da e-redes (dividir por 4) tem de bater certo

Vou voltar a fazer isso

nikito7, 2023-08-03:
Os gráficos diários usam as leituras

nikito7, 2023-08-03:
EB1:

1,01441dx8x4xxUUuuUUuu@i7:1000,LP Import Inc,kWh,LP3_IMP,3
; lp4
; lp5
1,01441dx8x8x8xxUUuuUUuu@i7:1000,LP Export Inc,kWh,LP6_EXP,3

EB3:

1,01441dx8x4xxUUuuUUuu@i7:1000,LP Import Inc,kWh,LP3_IMP,3
;
1,01441dx8x8x8xxUUuuUUuu@i7:1000,LP Export Inc,kWh,LP6_EXP,3

#

jgracio, 2023-08-03:
A e-redes apenas tem disponível 2 dias em Agosto
Os gráficos da energia importada coincidem

E estes são os da exportada

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

jgracio, 2023-08-03:
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

Já tinha verificado essas linhas carater a carater. Estão iguais ao que tens aqui no github

jgracio, 2023-08-03:
> Os gráficos diários usam as leituras.
>
> Entre o lp3 e o lp6 existe as reativas. Posso estar a ler a coisa errada

Poderá ser uma possibilidade.... mas será um problema apenas no caso do meu contador?

nikito7, 2023-08-03:
Começo a achar que é o contador.

Esses gráficos são gerados dos .csv

O 0d.csv pode ser errático

Os LP-xxxx.csv deveriam ser precisos.
Excepto que pode faltar linhas ou duplicar, em raras excepções

nikito7, 2023-08-03:
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

Pode não ter a ordem correcta.

É uma questão de ver em hex.

Sensor53 d1

A linha 0144

jgracio, 2023-08-03:
22:36:17.795 > 01 44 06 01 83 ad
22:36:17.898 : 01 44 1d 07 e7 08 03 04 16 1e 00 00 80 00 80 00 00 00 00 02 00 00 00 00 00 00 00 00 00 00 00 00

jgracio, 2023-08-03:
Agora tenho que fazer Sensor53 d0   ?

> 1d 07 e7 08 03 04 16 1e

Nesta altura a exportação está a zero

nikito7, 2023-08-03:
> 22:36:17.795 > 01 44 06 01 83 ad
> 22:36:17.898 : 01 44 1d 07 e7 08 03 04 16 1e 00 00 80 00 80 00 00 00 00 02 00 00 00 00 00 00 00 00 00 00 00 00

A linha não está completa

> Agora tenho que fazer Sensor53 d0 ?

Sim

jgracio, 2023-08-03:
Há alguma forma de enviar o output para um ficheiro de texto?

jgracio, 2023-08-03:
22:52:12.162 > 01 44 06 01 83 ad
22:52:12.268 : 01 44 1d 07 e7 08 03 04 16 2d 00 00 80 00 80 00 00 00 00 02 00 00 00 00 00 00 00 00 00 00 00 00
22:52:12.310 : 12 36

nikito7, 2023-08-03:
> Há alguma forma de enviar o output para um ficheiro de texto?

Só syslog ou http acho eu

nikito7, 2023-08-03:
> 22:52:12.162 > 01 44 06 01 83 ad 22:52:12.268 : 01 44 1d 07 e7 08 03 04 16 2d 00 00 80 00 80 00 00 00 00 02 00 00 00 00 00 00 00 00 00 00 00 00 22:52:12.310 : 12 36

01 44 1d
07 e7 08 03 04 16 2d 00 00 80 00 80 clock
00 amr status
00 00 00 02 lp3
00 00 00 00 lp4
00 00 00 00 lp5
00 00 00 00 lp6
12 36 crc

jgracio, 2023-08-03:
lp3 importada e lp6 exportada?

nikito7, 2023-08-03:
> lp3 importada e lp6 exportada?

Sim. A meio as reativas.

A 7 e 8 nao peço

jgracio, 2023-08-03:
para mim já estou a entrar em áreas transcendentais 😃

jgracio, 2023-08-03:
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

daí o endereço lido ser mais curto

jgracio, 2023-08-03:
r01440601

nikito7, 2023-08-03:
O tasmota não aguentava tudo. Nao sei se esse bug ainda existe.

01 44 08 01 ou simplesmente 01 44 00 01 salvo erro

nikito7, 2023-08-03:
https://github.com/nikito7/edpbox-dev/blob/dev/DEF-C44-509.pdf

jgracio, 2023-08-03:
Pois, transcendental para mim.
Amanhã vou ver se consigo estar à espreita quando estiver a exportar.

Obrigado pela ajuda

jgracio, 2023-08-04:
Desculpa insistir com este assunto:

Sendo a estrutura da linha:
01 44 1d
07 e7 08 03 04 16 2d 00 00 80 00 80 clock
00 amr status
00 00 00 02 lp3
00 00 00 00 lp4
00 00 00 00 lp5
00 00 00 00 lp6
12 36 crc

O filtro de extracção do LP6 está correto?
1,01441dx8x8x8xxUUuuUUuu@i7:1000,LP Export Inc,kWh,LP6_EXP,3

nikito7, 2023-08-04:
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

> O filtro de extracção do LP6 está correto?
> 1,01441dx8x8x8xxUUuuUUuu@i7:1000,LP Export Inc,kWh,LP6_EXP,3

8+8+8+1

Acho que sim

jgracio, 2023-08-04:
A energia exportada é o LP4.
Alterei o script para
1,01441dx8x8xxUUuuUUuu@i7:1000,LP Export Inc,kWh,LP6_EXP,3

E funciona às mil maravinhas.

Depreendo que os diagramas diários (hoje, ontem e anteontem) vão buscar os dados horários diretamente ao contador

nikito7, 2023-08-04:
É porque mudaram as coisas

nikito7, 2023-08-04:
01 44 1d
07 e7 08 04 05 0d 0f 00 00 80 00 80
00
00 00 00 07 - 7 hW
00 00 00 00
00 00 00 00
00 00 02 2a - 554 Wh
e9 ea - crc

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

E agora quem está certo? 🤣🤷‍♂️

nikito7, 2023-08-04:
> Depreendo que os diagramas diários (hoje, ontem e anteontem) vão buscar os dados horários diretamente ao contador

Sim Energy Import kWh

nikito7, 2023-08-04:
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

jgracio, 2023-08-04:
12:15:53.893
 01 44 06 01 83 ad
01 44 1d
 07 e7 08 04 05 0c 0f 00 00 80 00 80
 00
 00 00 00 00 -> 0Wh
 00 00 02 1f ->543Wh
 00 00 00 00
 00 00 00 0e
93 b9

nikito7, 2023-08-04:
Isso só tu podes confirmar

jgracio, 2023-08-04:
Confirmei com a integração da potencia e bater certo com os Wh. Certamente baterá certo com a informação da e-redes mas só amanhã consiguirei confirmar

jgracio, 2023-08-05:
Confirmado.
Para o meu contador Kaifa MA109P a leitura correta para o LP de exportação é:
1,01441dx8x8xxUUuuUUuu@i7:1000,LP Export Inc,kWh,LP6_EXP,3

Obrigado @nikito7 pelo teu excelente trabalho com o Easyhan e pelo ajuda que me deste neste troubleshooting

nikito7, 2023-08-05:
Isso é uma solução caso a caso.

Para manter o resto do script funcional.

É  o melhor sitio para alterar

Closed 2023-08-05.

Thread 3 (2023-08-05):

HA 2023.8 - 2024.2.0 mqtt

nikito7, 2023-08-05:
Ficheiros actualizados:

http://u.easyhan.pt/setup/EB1/

Ou no github.

Seguir os seguintes passos para evitar duplicados:

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

Feito pela ordem correcta, deve ficar tudo na mesma...

nikito7, 2023-08-05:
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

nikito7, 2023-08-09:
> tambem é preciso mexer nos yamls?

Sim, deixar de os usar

Closed 2023-11-05.

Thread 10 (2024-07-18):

[Sugestão] Alterar ficheiros de setup para permitir uso em casos que utilizam "reverse proxy" (e.g. nginx proxy_pass)

njascgil, 2024-07-18:
Viva!
Tenho usado o Easy HAN com um endereço do tipo http://dominio.org/tasmota/... sem qualquer problema, até ao momento em que atualizei para a configuração que inclui os diagramas.
Neste caso, por causa das várias referências a "/ufs/", as páginas dos diagramas deixam de funcionar.
Consegui resolver deste lado a situação procurando as referências a "/ufs" e substituindo por "../ufs" todas elas, excepto as do script, onde usei "./ufs". Também alterei referências a "/" para "../" em dois ficheiros.
Tanto quanto me apercebi, esta alteração não parece ter nenhum efeito secundário.
Os ficheiros modificados (V2, EB1, 13-jul) estão aqui ([mod.zip](https://github.com/user-attachments/files/16285558/mod.zip)), caso se confirme a vantagem de implementar estas alterações.

nikito7, 2024-08-27:
Feito. Acho eu

njascgil, 2024-08-27:
Obrigado! Acabei de testar e parece-me tudo ok. A solução adotada é até um pouco mais simples que a da minha sugestão... ;-)

A única coisa que reparei não funcionar, mas também não funcionava com a alteração que sugeri, é a edição/criação de ficheiros no ufs (links com terminações do tipo /ufse?file=/0d.csv), pois dá um erro 404 ao premir "Save". Não é importante, pois deve ser pouco usado, e imagino que deverá implicar mudar algo no firmware...

Closed 2024-08-27.

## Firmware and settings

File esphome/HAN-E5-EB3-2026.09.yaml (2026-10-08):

# EB3

interval:
  - interval: 20s
    then:
      - lambda: |-
          if (id(edpbox_polling).state) {
              id(edpbox).update();
          }

esphome:
  name: han-e5-eb3
  friendly_name: HAN
  min_version: 2026.9.1
  on_boot:
    priority: -500
    then:
      - switch.turn_on: led_pin
      - delay: 7s
      - switch.turn_on: edpbox_polling
  project:
    name: easyhan.edpbox3-e5
    version: "3.08"

dashboard_import:
  package_import_url: github://nikito7/easyhan/esphome/HAN-E5-EB3-2026.09.yaml@dev
  import_full_config: true

esp8266:
  board: esp07s

#esp32:
#  flash_size: 8MB
#  variant: esp32c6
#  framework:
#    type: esp-idf
#    advanced:
#      loop_task_stack_size: 32768 # esp32

wifi:
  output_power: 15db
  #use_address: han-b5-eb1
  #use_address: 10.1.0.46
  #use_address: "fd6a:7ff7:c70:1:70fc:f12c:7c8d:6f80"

  #ssid: ssn-7
  ssid: !secret wifi_ssid
  password: !secret wifi_password
  #password: edpbox123

  ap:
    ssid: "Easy-HAN-EB99"
    password: edpbox123

captive_portal:

### ### ###

#network:
#  enable_ipv6: true

#openthread:
#  tlv: !secret thread_tlv
#  use_address: "fd6a:7ff7:c70:1:70fc:f12c:7c8d:6f80"

### ### ###

web_server:
  local: true
  version: 3
  
logger:
  level: verbose
  #level: debug
  baud_rate: 0 # esp8266

api:
  reboot_timeout: 33min

ota:
  - platform: esphome

time:
  - platform: homeassistant
    id: esptime

button:
  - platform: restart
    name: "ESP Restart"

###

switch:

  - platform: gpio
    id: led_pin
    pin:
      number: 2
      inverted: yes # C6 no
                   # esp07s yes

#ifdef ESP8266
#  digitalWrite(2, LOW);

#elif ESP32C6
#  digitalWrite(2, HIGH);

#elif ESP32S3
#  digitalWrite(39, LOW);



  - platform: template
    name: "ESP Polling"
    id: "edpbox_polling"
    optimistic: yes

###

#ifdef ESP8266
#define HAN_DIR 16
# tx 1
# rx 3

#elif HAN_S3_WS485RELAY
#define HAN_DIR 21
#define HAN_TX 17
#define HAN_RX 18

#elif ESP32S3
#define HAN_DIR 16
#define HAN_TX 15
#define HAN_RX 17

#elif ESP32C6
#define HAN_DIR 3
#define HAN_TX 5
#define HAN_RX 4

#else
#define HAN_DIR 18
#define HAN_TX 16
#define HAN_RX 17

uart:

  id: modbus_serial
  rx_pin: 3
  #  number: 4
  #  mode:
  #    input: true
  #    pullup: true
  tx_pin: 1
  baud_rate: 9600
  stop_bits: 1
  #stop_bits: 2 # ziv

modbus:
  flow_control_pin: 16
  id: modbus1
  uart_id: modbus_serial
  turnaround_time: 1000ms
  send_wait_time: 1800ms

modbus_controller:
  - id: edpbox
    update_interval: never
    address: 0x1
    setup_priority: -10
    offline_skip_updates: 3
    max_cmd_retries: 0
    continuous: true

###

sensor:

###

  - platform: template
    name: "ESP Free Heap"
    lambda: |-
      // arduino
      float heap = ESP.getFreeHeap();
      // idf
      //float heap = esp_get_free_heap_size();
      return heap / 1024.0;
    unit_of_measurement: "kB"
    icon: mdi:chip
    state_class: measurement
    entity_category: diagnostic

  - platform: wifi_signal
    name: "ESP Signal"
    unit_of_measurement: "dB"
    state_class: measurement
    entity_category: diagnostic

  - platform: uptime
    name: "ESP Uptime"
    filters:
      - lambda: return x/3600;
    unit_of_measurement: "h"
    accuracy_decimals: 1
    device_class: ""
    entity_category: diagnostic

### ### ###

### Voltage & Current ###

  - platform: modbus_controller
    name: "Voltage L1"
    address: 0x006C
    unit_of_measurement: "V"
    register_type: read
    value_type: U_WORD
    accuracy_decimals: 1
    filters:
      - multiply: 0.1
      - filter_out: nan
    device_class: voltage
    state_class: measurement
    on_value:
      - then:
        - switch.turn_on: led_pin
        - delay: 30ms
        - switch.turn_off: led_pin

  - platform: modbus_controller
    name: "Current L1"
    address: 0x006D
    unit_of_measurement: "A"
    register_type: read
    value_type: U_WORD
    accuracy_decimals: 1
    filters:
      - multiply: 0.1
      - filter_out: nan
    device_class: current
    state_class: measurement

  - platform: modbus_controller
    name: "Voltage L2"
    address: 0x006E
    unit_of_measurement: "V"
    register_type: read
    value_type: U_WORD
    accuracy_decimals: 1
    filters:
      - multiply: 0.1
      - filter_out: nan
    device_class: voltage
    state_class: measurement

  - platform: modbus_controller
    name: "Current L2"
    address: 0x006F
    unit_of_measurement: "A"
    register_type: read
    value_type: U_WORD
    accuracy_decimals: 1
    filters:
      - multiply: 0.1
      - filter_out: nan
    device_class: current
    state_class: measurement

  - platform: modbus_controller
    name: "Voltage L3"
    address: 0x0070
    unit_of_measurement: "V"
    register_type: read
    value_type: U_WORD
    accuracy_decimals: 1
    filters:
     - multiply: 0.1
     - filter_out: nan
    device_class: voltage
    state_class: measurement
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

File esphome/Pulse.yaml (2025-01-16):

# Pulse Counter
# Binary Counter (TI HC4040)

substitutions:
  dev: Pulse
  name: pulse

globals:
   - id: cubic
     type: float
     restore_value: yes
     initial_value: '0.001' 

#deep_sleep:
#  id: sleep1
#  run_duration: 55s
#  sleep_duration: 5min
#  wakeup_pin: 7
#  wakeup_pin_mode: KEEP_AWAKE

esphome:
  name: ${name}
  project:
    name: easyhan.pulse-hc
    version: "1.29"
  on_boot:
    priority: 500
    then:
      - lambda: |-
          pinMode(5, INPUT_PULLDOWN);
          pinMode(6, INPUT_PULLDOWN);
          pinMode(7, INPUT_PULLDOWN);
          pinMode(8, INPUT_PULLDOWN);
          pinMode(9, INPUT_PULLDOWN);
          pinMode(10, INPUT_PULLDOWN);
          pinMode(11, INPUT_PULLDOWN);
          pinMode(12, INPUT_PULLDOWN);
          pinMode(13, INPUT_PULLDOWN);
          pinMode(14, INPUT_PULLDOWN);
          pinMode(15, INPUT_PULLDOWN);
          pinMode(16, INPUT_PULLDOWN);
          //
          pinMode(17, OUTPUT);
          digitalWrite(17, LOW);
          //
          pinMode(39, OUTPUT);
          digitalWrite(39, LOW);


dashboard_import:
  package_import_url: github://nikito7/easyhan/esphome/Pulse.yaml@dev
  import_full_config: true

esp32:
  board: esp32-s3-devkitc-1 # N8
  framework:
    type: arduino
  flash_size: 8MB
  variant: esp32s3

wifi:
  output_power: 15db
  #use_address: 10.1.0.39

  ssid: !secret wifi_ssid
  password: !secret wifi_password
  #password: edpbox123

  ap:
    ssid: "Easy-HAN-${dev}"
    password: edpbox123
    ap_timeout: 20s # change me

captive_portal:

###

###

#esp32_ble_tracker:
#bluetooth_proxy:

###

web_server:
  local: true
  version: 3
  
logger:
  level: debug
  #level: verbose

api:
  reboot_timeout: 45min

ota:
  - platform: esphome

time:
  - platform: homeassistant
    id: esptime

## ## ##

button:

  - platform: restart
    name: "${dev} ESP Restart"

#  - platform: template
#    name: "${dev} ESP Prevent Sleep"
#    on_press:
#      then:
#        - deep_sleep.prevent: sleep1


#  - platform: template
#    name: "${dev} HC Reset"
#    on_press:
#      then:
#        - lambda: |-
#            digitalWrite(17, HIGH);
#            delay(1);
#            digitalWrite(17, LOW);

## ## ##

# number: 12 id: qq_a
# number: 5  id: qq_b
# number: 6  id: qq_c
# number: 7  id: qq_d
# number: 9  id: qq_e
# number: 10 id: qq_f
# number: 8  id: qq_g
# number: 14 id: qq_h
# number: 13 id: qq_i
# number: 15 id: qq_j
# number: 16 id: qq_k
# number: 11 id: qq_l

## ## ##

sensor:

  - platform: template
    name: "${dev} HC Debug"
    lambda: |-
        // bits
        bool qq_a = digitalRead(12);
        bool qq_b = digitalRead(5);
        bool qq_c = digitalRead(6);
        bool qq_d = digitalRead(7);
        bool qq_e = digitalRead(9);
        bool qq_f = digitalRead(10);
        bool qq_g = digitalRead(8);
        bool qq_h = digitalRead(14);
        bool qq_i = digitalRead(13);
        bool qq_j = digitalRead(15);
        bool qq_k = digitalRead(16);
        bool qq_l = digitalRead(11);
        //
        char qq_dbg[24];
        sprintf(qq_dbg, "%d%d%d%d%d%d%d%d%d%d%d%d",
            qq_l, qq_k, qq_j, qq_i,
            qq_h, qq_g, qq_f, qq_e,
            qq_d, qq_c, qq_b, qq_a );
        id(counter_t).publish_state(qq_dbg);
        // n to a order
        uint16_t hc_pulse = 0;
        hc_pulse = (
          (qq_l << 11)
        | (qq_k << 10)
        | (qq_j << 9)
        | (qq_i << 8)
        | (qq_h << 7)
        | (qq_g << 6)
        | (qq_f << 5)
        | (qq_e << 4)
        | (qq_d << 3)
        | (qq_c << 2)
        | (qq_b << 1)
        |  qq_a
        );
        // led blink on
        digitalWrite(39, LOW);
        //
        uint16_t inc = hc_pulse;
        // sum HC4040
        if (hc_pulse >= 1) {
          float total = id(cubic);
          id(cubic) = total + (hc_pulse / 1000.0);
          delay(10);
          id(water_total).update();
          // reset
          digitalWrite(17, HIGH);
          delay(10);
          digitalWrite(17, LOW);
        }
        // led blink off
        delay(10);
        digitalWrite(39, HIGH);
        // value
        return inc;
    accuracy_decimals: 0
    state_class: measurement
    update_interval: 15s
    icon: "mdi:information"

###

  - platform: template
    name: "${dev} Water Total"
    id: water_total
    lambda: |-
        float a = id(cubic);
        return a;
    accuracy_decimals: 3
    device_class: water
    state_class: total_increasing
    unit_of_measurement: "m³"
    update_interval: 15s

###

  - platform: template
    name: "${dev} Wakeup Cause"
    accuracy_decimals: 0
    lambda: return esp_sleep_get_wakeup_cause();
    icon: "mdi:information"
    update_interval: 15s
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

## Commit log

2023-06-03 Update eb3-discovery1.txt
    Button
2023-08-02 Update eb3-lp-netmetering.yaml
    * Adc Addon
2023-11-09 Sensor53 l2
2023-11-26 Gc power bug
2023-12-28 Add contracted power (simple version)
2023-12-28 Add units to contracted power
2024-01-13 Dynamic Power :: Easy-HAN-RS485.md
2024-06-07 Update and rename adc-helium-chirpstack.yaml to adc2-helium-chirpstack.yaml
2024-09-25 ESP32-C6 support - eb3test.yaml
2025-01-20 Update HAN-C6-B5.yaml
    * remove i2c
2025-06-03 rename files dirs
    [E5.3-oshw_BOM.csv, E5.3-oshw_Export_Altium.pcbdoc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]
